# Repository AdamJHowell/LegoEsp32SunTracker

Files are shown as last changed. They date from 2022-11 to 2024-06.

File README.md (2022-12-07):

# Lego ESP32 Sun Tracker

This is a simple sun tracker, made using Lego Technic pieces for the structural components, and using Lego-compatible servos to control azimuth and altitude.  
Control will use the standard [Horizontal coordinate system](https://en.wikipedia.org/wiki/Horizontal_coordinate_system).

## Libraries

[PubSubClient by Nick O’Leary](https://pubsubclient.knolleary.net/)

[ESP32 Servo](https://github.com/madhephaestus/ESP32Servo) - [Documentation](https://madhephaestus.github.io/ESP32Servo/annotated.html)

A servo library tutorial is described [here](https://dronebotworkshop.com/esp32-servo/)

[Arduino JSON by Benoît Blanchon](https://arduinojson.org/)

## Green Servo Specifications:

| Characteristic | Value |
|---|---|
| Color: | green |
| Torsion: | 0.7kg |
| Operating voltage | 4.8-6V |
| Use Angle: | 360 degrees, continuous |
| Limit angle: | None |
| Operating travel: | 360° ±10° (in 500 → 2500 μsec) |
| PWM signal: | 500-2500 |
| Product speed | 160/min @ 6V |
| Gear reduction ratio | 1:140 |
| Wire length: | 25 cm |
| Terminal type: | DuPont terminal |

## Gray Servo Specifications:

### Electrical Specification (Function of the Performance)：

| Characteristic | 4.8V | 6.0V |
|---|---|---|
| Operating speed (at no load) | 0.14 ±0.01 sec/60° | 0.12 ±0.01 sec/60° |
| Running current (at no load) | 70 ±20 mA | 90 ±20 mA |
| Stall torque (at locked) | 1.8 ±0.2 kg-cm | 2 ±0.2 kg-cm |
| Stall current (at locked) | 0.8 ±0.1 A | 0.9 ±0.1 A |
| Idle current (at stopped) | 7 ±1 mA | 7 ±1 mA |
| Running life(at no load) | > 50,000 times | > 40,000 times |
| Temperature drift(at 25°C) | ≤ 1° | ≤ 1° |

### Mechanical Specification：

| Characteristic | value |
|---|---|
| Limit angle: | 360° |
| Weight | 20 ±1g |
| Horn gear spline: | Cross hole double output (1 Lego unit deep) |
| Reduction ratio: | 1/300 |
| excessive play: | ≤ 1° |
| Control system: | Change the pulse width |
| Amplifier type: | Digital controller |
| Operating travel: | 360° ±10° (in 500 → 2500 μsec) |
| Left&Right travelling:  | ≤ 10° |
| Centering deviation: | ≤ 2° |
| Neutral position: | 1500 μsec |
| Dead bandwidth: | ≤ 4 μsec |
| Rotating direction: | counter-clockwise (1500 → 500 μsec) |
| Pulse width range: | 500 → 2500 μsec |
| Maximum travel | 360°(500 → 2500 μsec) |
| Shock resistance: | 250 ±30g |
| Storage Temperature | -20°C - 60°C |
| Operating Temperature | -10°C - 50°C |

### Standard Test Environment

Every test at temperature: 25 ±5° C and relative humidity: 65 ±10％.

## MQTT messages

Move servo examples:

    {
    	"command":   "moveServo",
    	"servoName": "altitude",
    	"value":     42
    }

    {
    	"command":   "moveServo",
    	"servoName": "azimuth",
    	"value":     -42
    }

Topic: sunTracker/commands  
Valid "servoName" values are "azimuth" and "altitude".  
For altitude, valid values are integers from 0 to 'altitudeMaxAngle', where those values represent the angle. The servo is capable of rotation between 0° and 360°, but this is being constrained in this program to prevent mechanical interference with other structures. If values outside that range are provided, they will be constrained to the nearest valid value before passed to the servo.  
For azimuth, valid values are integers from -100 to 100, where those values represent percentages of maximum speed. Positive values will rotate clockwise when viewed from above. Negative values will rotate counterclockwise when viewed from above. If values outside that range are provided, they will be constrained to the nearest valid value before passed to the servo.

## LED

The LED now indicates the status of the Wi-Fi and MQTT connections. It has three states:

* An extinguished LED means Wi-Fi is not connected.
* A blinking LED means Wi-Fi is connected, but there is no connection to the MQTT broker.
* An illuminated LED means both Wi-Fi and MQTT are connected.

### ToDo:

* Modify the Wi-Fi connection code to use callbacks, so it no longer blocks.
* Modify the MQTT connection code to not block.

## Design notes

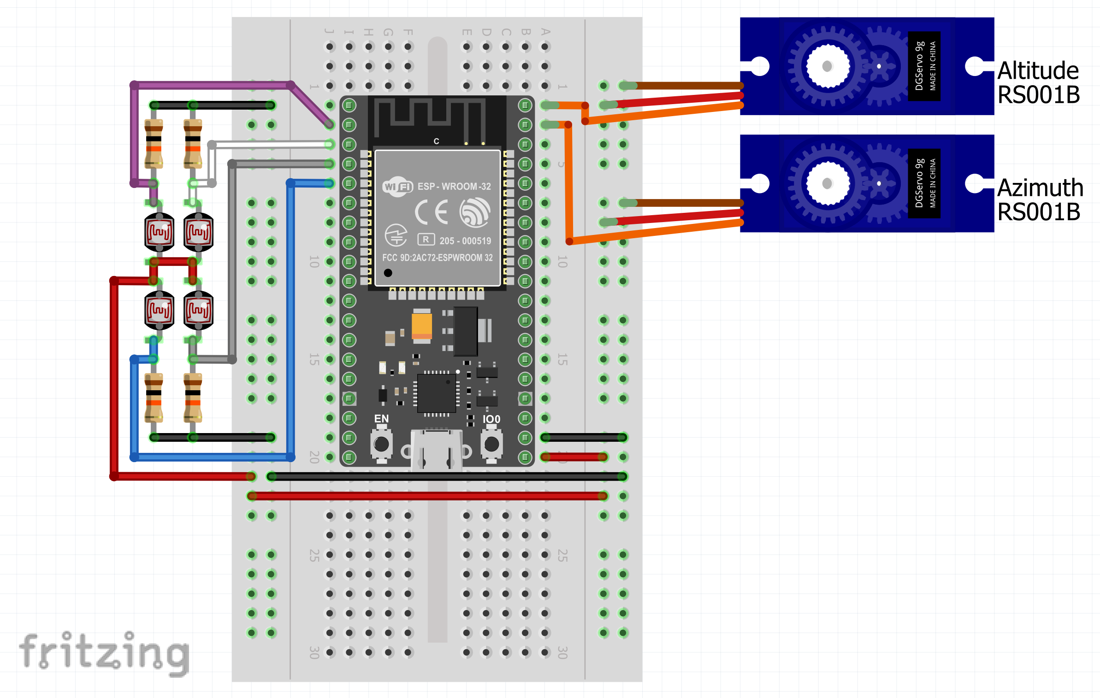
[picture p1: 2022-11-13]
Fritzing Lego ESP32 Sun Tracker.png

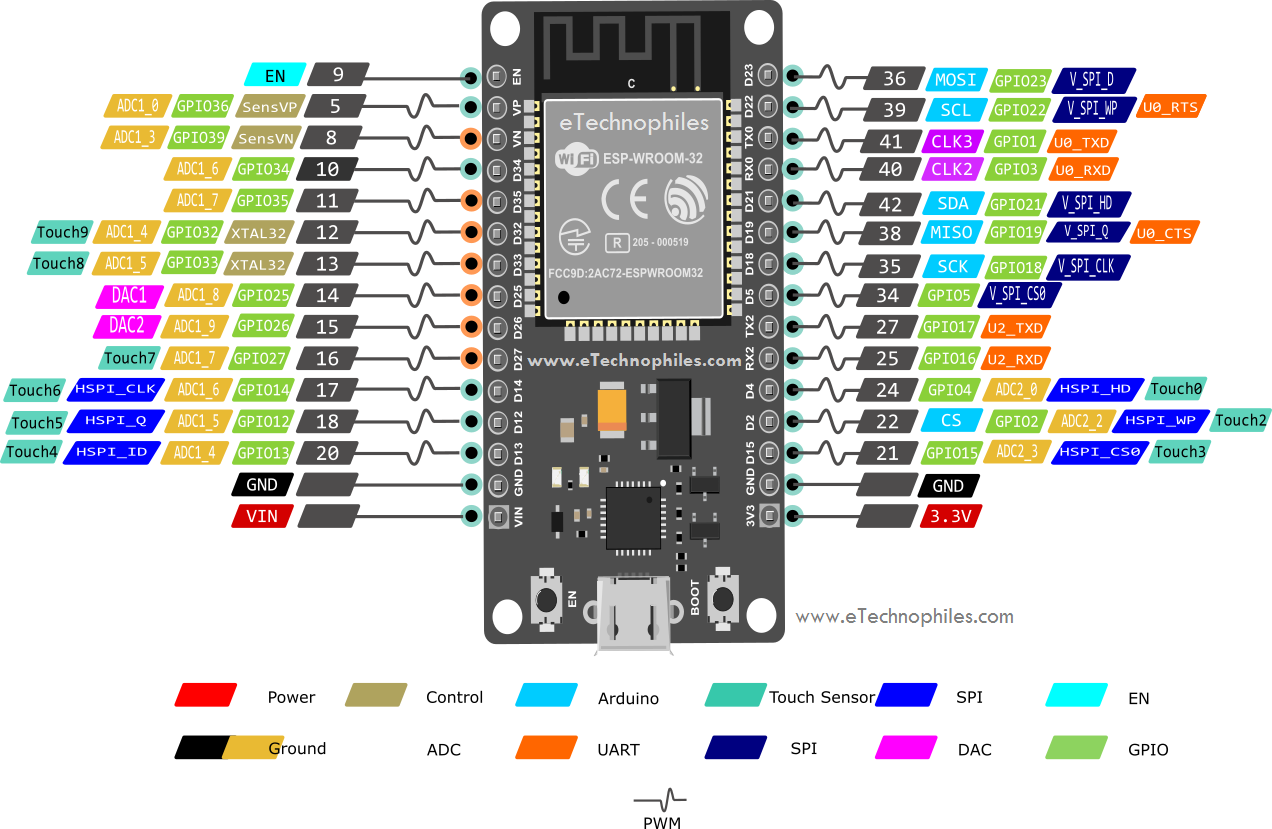
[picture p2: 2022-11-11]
ESP32 30 pin Wroom32.png

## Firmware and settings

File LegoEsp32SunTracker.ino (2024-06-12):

/**
 * LegoEsp32SunTracker is a simple sun tracker built with an ESP32 and Lego Technic components.
 * See README.md for details.
 */
#include "LegoEsp32SunTracker.h"


// ToDo: Move the altitude proportional to the upperSum/lowerSum delta.
// ToDo: Move the azimuth proportional to the leftSum/RightSum delta.


/**
 * @brief readTelemetry() will gather basic device information and store those values in global variables.
 */
void readTelemetry()
{
   rssi = WiFi.RSSI();
   upperLeftValue = analogRead( upperLeftGPIO );
   upperRightValue = analogRead( upperRightGPIO );
   lowerLeftValue = analogRead( lowerLeftGPIO );
   lowerRightValue = analogRead( lowerRightGPIO );
} // End of readTelemetry() function.


/**
 * @brief printTelemetry() will print basic device information to the serial port.
 */
void printTelemetry()
{
   Serial.println();
   printCount++;
   Serial.println( __FILE__ );
   Serial.printf( "Print count %ld\n", printCount );
   Serial.println();

   Serial.println( "Network stats:" );
   Serial.printf( "  MAC address: %s\n", macAddress );
   int wifiStatusCode = WiFi.status();
   char buffer[29];
   lookupWifiCode( wifiStatusCode, buffer );
   if( wifiStatusCode == 3 )
   {
      Serial.printf( "  IP address: %s\n", ipAddress );
      Serial.printf( "  RSSI: %ld\n", rssi );
      Serial.print( "~~IP address: " );
      Serial.println( WiFi.localIP() );
   }
   Serial.printf( "  wifiConnectCount: %u\n", wifiConnectCount );
   Serial.printf( "  wifiCoolDownInterval: %lu\n", wifiCoolDownInterval );
   Serial.printf( "  Wi-Fi status text: %s\n", buffer );
   Serial.printf( "  Wi-Fi status code: %d\n", wifiStatusCode );
   Serial.println();

   Serial.println( "MQTT stats:" );
   Serial.printf( "  mqttConnectCount: %u\n", mqttConnectCount );
   Serial.printf( "  mqttCoolDownInterval: %lu\n", mqttCoolDownInterval );
   if( mqttClient.connected() )
      Serial.printf( "  Broker: %s:%d\n", mqttClient.getServerDomain(), mqttClient.getServerPort() );
   lookupMQTTCode( mqttClient.state(), buffer );
   Serial.printf( "  MQTT state: %s\n", buffer );
   Serial.printf( "  Publish count: %lu\n", publishCount );
   Serial.printf( "  Callback count: %lu\n", callbackCount );
   Serial.println();

   Serial.println( "Device stats:" );
   Serial.printf( "  Altitude servo speed: %d\n", altitudeSpeed );
   Serial.printf( "  Azimuth servo speed: %d\n", azimuthSpeed );
   Serial.println();
   int upperSum = upperLeftValue + upperRightValue;
   int lowerSum = lowerLeftValue + lowerRightValue;
   int leftSum = upperLeftValue + lowerLeftValue;
   int rightSum = upperRightValue + lowerRightValue;
   Serial.println( "  Analog readings:" );
   Serial.printf( " ------|------\n" );
   Serial.printf( "| %4d | %4d |-- %4d\n", upperLeftValue, upperRightValue, upperSum );
   Serial.printf( "|------|------|\n" );
   Serial.printf( "| %4d | %4d |-- %4d\n", lowerLeftValue, lowerRightValue, lowerSum );
   Serial.printf( " ---|--|---|--\n" );
   Serial.printf( "    |      |\n" );
   Serial.printf( "  %4d   %4d\n", leftSum, rightSum );
   Serial.println();

   Serial.printf( "Upper - Lower = %d\n", upperSum - lowerSum );
   Serial.printf( "Left - Right = %d\n", leftSum - rightSum );

   if( abs( upperSum - lowerSum ) > 50 )
   {
      if( upperSum < lowerSum )
         Serial.println( "Move up!" );
      else
         Serial.println( "Move down!" );
   }
   else
      Serial.println( "Altitude hold!" );

   if( abs( leftSum - rightSum ) > 50 )
   {
      if( leftSum < rightSum )
         Serial.println( "Move left!" );
      else
         Serial.println( "Move right!" );
   }
   else
      Serial.println( "Azimuth hold!" );

   Serial.printf( "inclinationStopPin: %d\n", digitalRead( inclinationStopPin ) );
   Serial.printf( "declinationStopPin: %d\n", digitalRead( declinationStopPin ) );
   Serial.printf( "altitudeSpeed: %d\n", altitudeSpeed );
   Serial.printf( "azimuthSpeed: %d\n", azimuthSpeed );

   char valueBuffer[25] = "";
   snprintf( valueBuffer, 25, "%d", altitudeSpeed );
   mqttClient.publish( "LegoSunTracker/altitudeSpeed", valueBuffer );
   snprintf( valueBuffer, 25, "%d", azimuthSpeed );
   mqttClient.publish( "LegoSunTracker/azimuthSpeed", valueBuffer );

   snprintf( valueBuffer, 25, "%d", upperLeftValue );
   mqttClient.publish( "LegoSunTracker/upperLeftValue", valueBuffer );
   snprintf( valueBuffer, 25, "%d", upperRightValue );
   mqttClient.publish( "LegoSunTracker/upperRightValue", valueBuffer );
   snprintf( valueBuffer, 25, "%d", lowerLeftValue );
   mqttClient.publish( "LegoSunTracker/lowerLeftValue", valueBuffer );
   snprintf( valueBuffer, 25, "%d", lowerRightValue );
   mqttClient.publish( "LegoSunTracker/lowerRightValue", valueBuffer );

   Serial.printf( "Next telemetry poll in %lu seconds\n", telemetryPrintInterval / MILLIS_IN_SEC );
   Serial.println( "\n" );
} // End of printTelemetry() function.


void setup()
{
   delay( 1000 );
   // Start the Serial communication to send messages to the computer.
   Serial.begin( 115200 );
   if( !Serial )
      delay( 1000 );
   Serial.println( "\n\nsetup() is beginning." );

   // Allocate all timers.
   ESP32PWM::allocateTimer( 0 );
   ESP32PWM::allocateTimer( 1 );
   ESP32PWM::allocateTimer( 2 );
   ESP32PWM::allocateTimer( 3 );

   // Standard 50 hz servo.
   altitudeServo.setPeriodHertz( 50 );
   // Connects the servo object to GPIO 22, sets 500 μsec as the minimum pulse width and 2500 μsec as the maximum pulse width.
   altitudeServo.attach( altitudeServoPin, minPulseWidth, maxPulseWidth );
   //	setAltitude( altitudePosition );
   setAltitudeSpeed( altitudeSpeed );

   // Standard 50 hz servo.
   azimuthServo.setPeriodHertz( 50 );
   // Connects the servo object to GPIO 23, sets 500 μsec as the minimum pulse width and 2500 μsec as the maximum pulse width.
   azimuthServo.attach( azimuthServoPin, minPulseWidth, maxPulseWidth );
   setAzimuthSpeed( azimuthSpeed );

   // Limit switches.
   pinMode( declinationStopPin, INPUT );
   pinMode( inclinationStopPin, INPUT );

   // Set GPIO 2 (MCU_LED) as an output.
   pinMode( MCU_LED, OUTPUT );
   // Turn the LED on.
   digitalWrite( MCU_LED, LED_ON );

   // Set the MAC address variable to its value.
   snprintf( macAddress, 18, "%s", WiFi.macAddress().c_str() );

   wifiMultiConnect();

   configureOTA();

   Serial.println( "setup() has finished.\n" );
} // End of setup() function.


/**
 * @brief toggleLED() will change the state of the LED.
 * This function does not manage any timings.
 */
void toggleLED()
{
   if( digitalRead( MCU_LED ) != LED_ON )
      digitalWrite( MCU_LED, LED_ON );
   else
      digitalWrite( MCU_LED, LED_OFF );
} // End of toggleLED() function.


void loop()
{
   // Process OTA requests.
   ArduinoOTA.handle();

   // Poll the first time.  Poll every interval.
   if( lastTelemetryPollTime == 0 || ( millis() - lastTelemetryPollTime > telemetryPollInterval ) )
   {
      readTelemetry();
      lastTelemetryPollTime = millis();
   }

   //	Check the MQTT connection, and reconnect if needed.
   if( !mqttClient.connected() )
      mqttConnect();
   // The MQTT client loop() function facilitates the receiving of messages and maintains the connection to the broker.
   mqttClient.loop();

   // Process the first time.  Process every interval.
   if( lastTelemetryProcessTime == 0 || ( millis() - lastTelemetryProcessTime > telemetryProcessInterval ) )
   {
      moveArm();
      lastTelemetryProcessTime = millis();

      // If Wi-Fi is connected, but MQTT is not, blink the LED.
      if( WiFi.status() == WL_CONNECTED )
      {
         if( mqttClient.state() != 0 )
            toggleLED();
         else
            digitalWrite( MCU_LED, LED_ON );
      }
   }

   // Print the first time.  Print every interval.
   if( lastTelemetryPrintTime == 0 || ( millis() - lastTelemetryPrintTime > telemetryPrintInterval ) )
   {
      printTelemetry();
      lastTelemetryPrintTime = millis();
   }
} // End of loop() function.

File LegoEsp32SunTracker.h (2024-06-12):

/**
 * Created by Adam on 2022-10-08.
 */

#ifndef LEGO_ESP32_SUN_TRACKER_H
#define LEGO_ESP32_SUN_TRACKER_H

#ifdef ESP8266
// These headers are installed when the ESP8266 is installed in board manager.
#include <ESP8266WiFi.h> // ESP8266 WiFi support.  https://github.com/esp8266/Arduino/tree/master/libraries/ESP8266WiFi
#include <ESP8266mDNS.h> // OTA - mDNSResponder (Multicast DNS) for the ESP8266 family.
#define LED_ON  0
#define LED_OFF 1
#else
// These headers are installed when the ESP32 is installed in board manager.
#include <WiFi.h>    // ESP32 Wifi support.  https://github.com/espressif/arduino-esp32/blob/master/libraries/WiFi/src/WiFi.h
#include <ESPmDNS.h> // OTA - Multicast DNS for the ESP32.
#define LED_ON  1
#define LED_OFF 0
#endif
#include <WiFiUdp.h>      // OTA - The Arduino OTA library.  Specific version of this are installed along with specific boards in board manager.
#include <ArduinoOTA.h>   // OTA - The Arduino OTA library.  Specific version of this are installed along with specific boards in board manager.
#include <ArduinoJson.h>  // A JSON processing library.  Author: Benoît Blanchon  https://arduinojson.org/
#include "PubSubClient.h" // PubSub is the MQTT API maintained by Nick O'Leary: https://github.com/knolleary/pubsubclient
#include "privateInfo.h"  // I use this file to hide my network information from random people on GitHub.
#include "ServoFunctions.h"


/**
 * Function declarations.
 */
// NetworkFunctions.ino
void mqttCallback( char *topic, byte *payload, unsigned int length );
void configureOTA();
int checkForSSID( const char *ssidName );
bool wifiConnect( const char *ssid, const char *password );
void wifiMultiConnect();
void mqttConnect();
void lookupWifiCode( int code, char *buffer );
void lookupMQTTCode( int code, char *buffer );
// LegoEsp32SunTracker.ino
void readTelemetry();  // Not yet implemented.
void printTelemetry(); // Not yet implemented.


/**
 * Class objects.
 */
struct WiFiClient espClient;          // Create a WiFiClient to connect to the local network.
PubSubClient mqttClient( espClient ); // Create a PubSub MQTT client object that uses the WiFiClient.


/**
 * Global Network constants.
 * If you do not use the privateInfo.h file to hold your network information, you will need to set these five lines to suit your needs.
 */
//#define ELEMENT_COUNT 2
//const char *wifiSsidArray[ELEMENT_COUNT] = { "HomeWiFi", "WorkWiFi" };
//const char *wifiPassArray[ELEMENT_COUNT] = { "pass1", "pass2" };
//const char *mqttBrokerArray[ELEMENT_COUNT] = { "192.168.1.5", "10.10.10.27" };
//const int mqttPortArray[ELEMENT_COUNT] = { 1883, 1883 };


/**
 * Other global constants.
 */
const char *HOST_NAME = "LegoEsp32SunTracker";          // The hostname used for OTA access.
const char *SKETCH_NAME = "LegoEsp32SunTracker.ino";    // The name used when publishing stats.
const char *NOTES = "The ESP32 sun tracker";            // The hostname used for OTA access.
const char *MQTT_STATS_TOPIC = "sunTracker/stats";      // The topic this device will publish to upon connection to the broker.
const char *MQTT_COMMAND_TOPIC = "sunTracker/commands"; // The command topic this device will subscribe to.
const char *sketchTopic = "sunTracker/sketch";          // The topic used to publish the sketch name (__FILE__).
const char *MAC_TOPIC = "/mac";                         // The topic used to publish the MAC address.
const char *IP_TOPIC = "/ip";                           // The topic used to publish the IP address.
const char *RSSI_TOPIC = "/rssi";                       // The topic used to publish the Wi-Fi Received Signal Strength Indicator.
const char *TOPIC_PREFIX = "sunTracker/";               // The topic segment that comes before the MAC address.
const unsigned long JSON_DOC_SIZE = 512;                // The ArduinoJson document size, and size of some buffers.
const unsigned int MILLIS_IN_SEC = 1000;                // The number of milliseconds in one second.
const int upperLeftGPIO = 36;
const int upperRightGPIO = 39;
const int lowerLeftGPIO = 34;
const int lowerRightGPIO = 35;
int upperLeftValue = 0;
int upperRightValue = 0;
int lowerLeftValue = 0;
int lowerRightValue = 0;


/**
 * Global variables.
 */
char ipAddress[16];                          // A character array to hold the IP address.
char macAddress[18];                         // A character array to hold the MAC address, and append a dash and 3 numbers.
long rssi = 0;                               // A global to hold the Received Signal Strength Indicator.
unsigned int networkIndex = 2112;            // An unsigned integer to hold the correct index for the network arrays: wifiSsidArray[], wifiPassArray[], mqttBrokerArray[], and mqttPortArray[].
unsigned int wifiConnectionTimeout = 10000;  // Set the Wi-Fi connection timeout to 10 seconds.
unsigned int mqttReconnectInterval = 3000;   // When mqttMultiConnect is set to try multiple times, this is how long to delay between each attempt.
unsigned int mqttReconnectCooldown = 20000;  // Set the minimum time between calls to mqttMultiConnect() to 20 seconds.
unsigned int telemetryPollInterval = 20;     // How long to wait between sensor polling.
unsigned int telemetryProcessInterval = 200; // How long to wait between sensor processing.
unsigned int telemetryPrintInterval = 5000;  // How long to wait between sensor printing.
unsigned int publishInterval = 60000;        // How long to wait between MQTT publishes.
unsigned int callbackCount = 0;              // The number of times a callback was received.
unsigned int MCU_LED = 2;                    // The GPIO which the onboard LED is connected to.
const unsigned int ONBOARD_LED = 2;          // The GPIO which the onboard LED is connected to.
unsigned int wifiConnectCount = 0;           // A counter for how many times the wifiConnect() function has been called.
unsigned int mqttConnectCount = 0;           // A counter for how many times the mqttConnect() function has been called.
unsigned long publishCount = 0;              // A counter of how many times the stats have been published.
unsigned long lastTelemetryPollTime = 0;     // The last time sensors were polled.
unsigned long lastTelemetryProcessTime = 0;  // The last time sensor data was acted on.
unsigned long lastTelemetryPrintTime = 0;    // The last time sensor data was printed.
unsigned long lastPublishTime = 0;           // The last time a MQTT publish was performed.
unsigned long lastMqttConnectionTime = 0;    // The last time a MQTT connection was attempted.
unsigned long lastWifiConnectTime = 0;       // The last time a Wi-Fi connection was attempted.
unsigned long wifiCoolDownInterval = 10000;  // How long to wait between Wi-Fi connection attempts.
unsigned long mqttCoolDownInterval = 10000;  // How long to wait between MQTT broker connection attempts.
unsigned long printCount = 0;                // A counter of how many times the stats have been printed.


#endif // LEGO_ESP32_SUN_TRACKER_H

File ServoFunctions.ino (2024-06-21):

#include "LegoEsp32SunTracker.h"


/**
 * @brief The altitude servo is a continuous-rotation servo that needs to be constrained to keep the arm from rotating beyond 90°.
 * The allowed range will be from 0° to 'altitudeMaxAngle'°.
 * @param angle the angle to set the servo to.
 * Nothing in this function is blocking.
 */
void setAltitude( int angle )
{
   if( digitalRead( inclinationStopPin ) == 1 && digitalRead( declinationStopPin ) == 1 )
   {
      // Enforce constraints.
      if( angle < 0 )
         angle = 0;
      if( angle > altitudeMaxAngle )
         angle = altitudeMaxAngle;
      // Establish an adjusted maximum pulse width, to enforce a 0°-'altitudeMaxAngle'° range.
      int pwmRange = maxPulseWidth - minPulseWidth;
      // The constrained maximum range should be the minimum value plus 1/4 of the range.
      int modifiedMaxPulseWidth = minPulseWidth + ( pwmRange / 4 );
      // Map the angle to a pulse width.  Note that swapping 0 and altitudeMaxAngle will effectively reverse the servo.
      int pulseWidth = map( angle, 0, altitudeMaxAngle, minPulseWidth, modifiedMaxPulseWidth );
      // Set the servo to the resulting value.
      altitudeServo.writeMicroseconds( pulseWidth );
      //	Serial.printf( "Altitude position: %d, pulse width: %d\n\n", altitudePosition, pulseWidth );
   }
   else
      Serial.println( "Unable to raise/lower arm due to limit switch!" );
} // End of setAltitude() function.


/**
 * @brief The altitude servo is a continuous-rotation servo.
 * @param speed the speed (in percentage of maximum) to set the servo to.
 * Positive altitude values raise the panel.
 * Nothing in this function is blocking.
 */
void setAltitudeSpeed( int speed )
{
   // Enforce constraints.
   if( speed > 100 )
      speed = 100;
   if( speed < -100 )
      speed = -100;
   // Map the speed to a pulse width.
   int pulseWidth = map( speed, -100, 100, minPulseWidth, maxPulseWidth );
   // Set the servo to the resulting value.
   altitudeServo.writeMicroseconds( pulseWidth );
   //	Serial.printf( "Altitude speed: %d, pulse width: %d\n\n", speed, pulseWidth );
} // End of setAltitudeSpeed() function.


/**
 * @brief The azimuth servo is a continuous-rotation servo.
 * @param speed the speed to set the servo to.
 * Positive azimuth values rotate the device clockwise (to the right).
 * Nothing in this function is blocking.
 */
void setAzimuthSpeed( int speed )
{
   // Enforce constraints.
   if( speed > 100 )
      speed = 100;
   if( speed < -100 )
      speed = -100;
   // Map the speed to a pulse width.
   int pulseWidth = map( speed, -100, 100, minPulseWidth, maxPulseWidth );
   // Set the servo to the resulting value.
   azimuthServo.writeMicroseconds( pulseWidth );
   //	Serial.printf( "Azimuth speed: %d, pulse width: %d\n\n", speed, pulseWidth );
} // End of setAzimuthSpeed() function.


/**
 * @brief This function uses the analog readings (globals populated by the readTelemetry() function) to determine the servos PWM values.
 * Nothing in this function is blocking.
 */
void moveArm()
{
   int upperSum = upperLeftValue + upperRightValue;
   int lowerSum = lowerLeftValue + lowerRightValue;
   int leftSum = upperLeftValue + lowerLeftValue;
   int rightSum = upperRightValue + lowerRightValue;

   //	int tempAlt = map( upperSum - lowerSum, -8190, 8190, 0, altitudeMaxAngle );
   //	int tempAz = map( leftSum - rightSum, -8190, 8190, -100, 100 );
   //	Serial.printf( "Altitude servo suggestion: %d\n", tempAlt );
   //	Serial.printf( "Azimuth servo suggestion : %d\n", tempAz );


   //	╭────────────╮
   //	│  Altitude  │
   //	╰────────────╯
   if( abs( upperSum - lowerSum ) > 2000 )
   {
      if( upperSum > lowerSum )
         altitudeSpeed = -60;
      else
         altitudeSpeed = 60;
   }
   else if( abs( upperSum - lowerSum ) > 1000 )
   {
      if( upperSum > lowerSum )
         altitudeSpeed = -40;
      else
         altitudeSpeed = 40;
   }
   else if( abs( upperSum - lowerSum ) > 500 )
   {
      if( upperSum > lowerSum )
         altitudeSpeed = -30;
      else
         altitudeSpeed = 30;
   }
   else if( abs( upperSum - lowerSum ) > 200 )
   {
      if( upperSum > lowerSum )
         altitudeSpeed = -20;
      else
         altitudeSpeed = 20;
   }
   else
      altitudeSpeed = 0;

   // Don't allow upwards movement if the inclination limit switch is shorted to ground.
   if( altitudeSpeed > 0 && digitalRead( inclinationStopPin ) == 0 )
      altitudeSpeed = 0;
   // Don't allow downward movement if the declination limit switch is shorted to ground.
   if( altitudeSpeed < 0 && digitalRead( declinationStopPin ) == 0 )
      altitudeSpeed = 0;
   setAltitudeSpeed( altitudeSpeed );


   //	╭───────────╮
   //	│  Azimuth  │
   //	╰───────────╯
   if( abs( leftSum - rightSum ) > 1000 )
   {
      if( leftSum > rightSum )
         azimuthSpeed = 100;
      else
         azimuthSpeed = -100;
   }
   else if( abs( leftSum - rightSum ) > 800 )
   {
      if( leftSum > rightSum )
         azimuthSpeed = 50;
      else
         azimuthSpeed = -50;
   }
   else if( abs( leftSum - rightSum ) > 400 )
   {
      if( leftSum > rightSum )
         azimuthSpeed = 30;
      else
         azimuthSpeed = -30;
   }
   else if( abs( leftSum - rightSum ) > 200 )
   {
      if( leftSum > rightSum )
         azimuthSpeed = 15;
      else
         azimuthSpeed = -15;
   }
   else
      azimuthSpeed = 0;
   setAzimuthSpeed( azimuthSpeed );
} // End of moveArm() function.

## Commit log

2022-10-07 CMakeLists.txt is almost working. Still cannot find the servo library.
2022-10-09 Renamed "elevation" to "altitude", to match the standard Horizontal coordinate system. Added functions to control the servos. Organized global variables into well-defined blocks. Improved comments. C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
2022-10-10 Printing servo positions to the terminal.
2022-10-10 Fixed the MAC address.
    [LegoEsp32SunTracker.ino]
2022-10-11 Reversed the altitude servo. Optimized imports. Moved the rssi read to readTelemetry().
    [LegoEsp32SunTracker.h, LegoEsp32SunTracker.ino, NetworkFunctions.ino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]
2022-10-11 Forgot some carriage returns.
2022-10-11 Added LED output for showing connectivity states.
2022-10-12 Still cannot connect to the broker.
    [LegoEsp32SunTracker.h, LegoEsp32SunTracker.ino, NetworkFunctions.ino]
2022-11-08 Fixed pretty much everything, so it now responds to MQTT commands. Does not have the analog-to-movement code yet.
    [LegoEsp32SunTracker.h, LegoEsp32SunTracker.ino, NetworkFunctions.ino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]
2022-11-11 Added a devkit pinout graphic and a Fritzing layout
    [LegoEsp32SunTracker.fzz]
2022-11-13 Create Fritzing Lego ESP32 Sun Tracker.png
2022-11-13 Added ADC code.
2022-11-13 Now reading the ADC values and moving the servos appropriately.
2022-11-14 Moved the servo control logic to the moveArm() function.
2022-11-14 Vast improvements to printouts. Found and commented-out the line that was causing the core panic. I'll deal with that later.
2022-11-15 Created a header file for servos.
2022-11-15 Added a timer for blinking the LED. The LED now indicates the status of the Wi-Fi and MQTT connections. An extinguished LED means Wi-Fi is not connected. A blinking LED means Wi-Fi is connected, but 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
    [LegoEsp32SunTracker.h, LegoEsp32SunTracker.ino, NetworkFunctions.ino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]
2022-11-16 Renamed the pin assignment variables. Updated the README.md file.
2022-11-16 Tweaks to how the serial output is printed.
2022-11-22 I have the code working with the new altitude servo and gear setup. However, I don't think that I'm getting the full 360° range of motion from that servo. It will not matter in a while, because that 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
    [LegoEsp32SunTracker.h, LegoEsp32SunTracker.ino, ServoFunctions.h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]
2022-12-12 Converted the altitude servo from standard to continuous rotation.
2023-04-16 Tinkering with servo speeds, and fixed the altitude stops (I think).
    [LegoEsp32SunTracker.h, LegoEsp32SunTracker.ino, NetworkFunctions.ino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]
2023-04-16 Tuned the elevation speeds and fixed the azimuth directions.
    [ServoFunctions.ino]
